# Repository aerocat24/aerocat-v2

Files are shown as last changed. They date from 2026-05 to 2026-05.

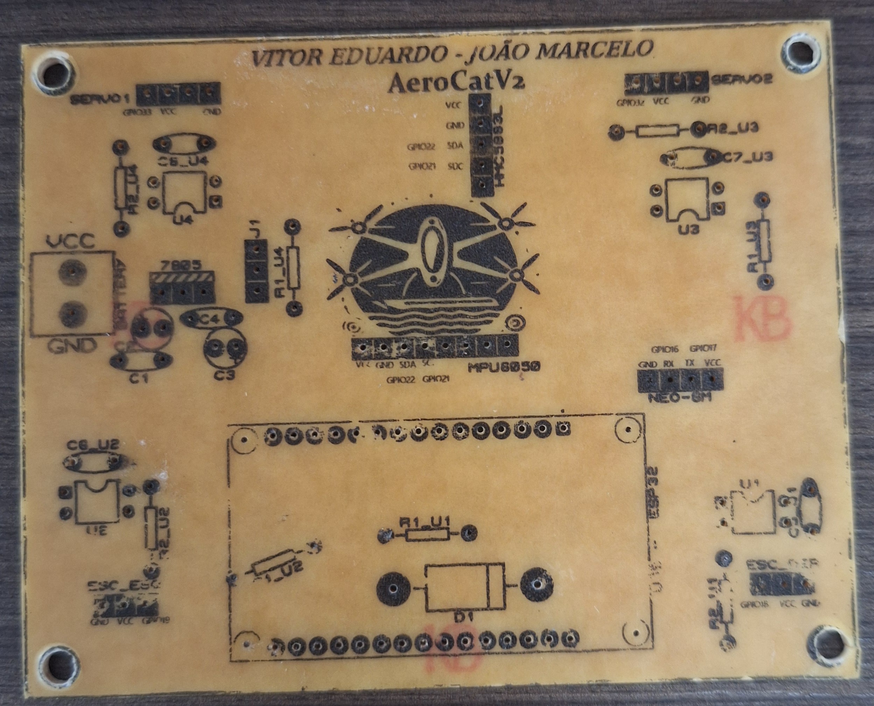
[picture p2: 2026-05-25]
PCB/images/without_components.jpg

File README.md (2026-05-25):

# ASV Aerocat V2

The **ASV Aerocat V2** is a small-scale autonomous surface vessel with a
catamaran hull and aerial propulsion. The project was developed for autonomous
navigation and for applications involving cooperation with aerial vehicles,
providing an accessible, low-cost platform for academic, educational, and
scientific research purposes.

## Development

The Aerocat V2 was developed by:

- [accaciofsantos](https://github.com/accaciofsantos)
- [joaomarcelors](https://github.com/joaomarcelors)
- [Vitaum-not](https://github.com/Vitaum-not)
- [vbschettino](https://github.com/vbschettino)

## Publications

Some results related to the project were presented in the following
publications:

- https://ieeexplore.ieee.org/document/10838066
- https://ieeexplore.ieee.org/document/11369526

## Repository Contents

This repository contains the main files required to build and replicate the
ASV Aerocat V2, including:

- assembly step-by-step instructions;
- STL files for the mechanical parts;
- PCB machining/fabrication files;
- project reference images.

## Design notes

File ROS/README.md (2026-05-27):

# ROS framework and package communication

This folder contains the ROS packages responsible for communication, navigation,
manual control, and cooperation between the AeroCat V2 ASV and the UAV. The
system was developed using ROS and operates through a Wi-Fi network connecting
the onboard computer, the ASV, and the UAV.

The framework enables autonomous navigation, real-time telemetry exchange,
remote operation, and cooperative missions such as UAV inspection and landing on
the moving ASV platform.

## ASV Quick start

### 1. Clone the repository

Clone the project to your machine:

```bash
git clone https://github.com/aerocat24/aerocat-v2.git
```

### 2. Flash the ESP32 firmware

The ESP32 firmware was developed using the PlatformIO plugin for VS Code. Open
VS Code, import the project located in the `boat_esp32` folder, build it, and
flash the firmware to your ESP32.

### 3. Build the ROS workspace

The project was developed using ROS Noetic. Go to the workspace:

```bash
cd aerocat-v2/ROS/boat_drone_ws
```

Build the workspace:

```bash
catkin build
```

### 4. Test the boat communication

With the ESP32 powered on and connected to the Wi-Fi network, start
`rosbridge`:

```bash
roslaunch rosbridge_server rosbridge_websocket.launch
```

In two other terminals, check whether the boat topics are being received:

```bash
rostopic echo /boat/compass
```

```bash
rostopic echo /boat/gps
```

If no data appears in the topics, check that:

- The computer and the ESP32 are connected to the same Wi-Fi network.
- The GPS module has signal. This is usually indicated by a blinking red light.

### 5. Check the joystick mapping

The joystick button mapping only needs to be checked once. To connect the
Bluetooth joystick to ROS, run:

```bash
roslaunch boat remote_control_joy.launch
```

In another terminal, monitor the joystick messages:

```bash
rostopic echo /boat/joy
```

Compare the received mapping with the one defined in
`remote_control_joy_node.py`. Then check whether the commands below are working
correctly:

| Control | Action |
| --- | --- |
| Left analog stick up | Sends PWM to the right motor |
| Right analog stick up | Sends PWM to the left motor |
| `L1` | Decreases the maximum power |
| `R1` | Increases the maximum power |
| `select` | Toggles between manual and autonomous mode |

When moving each analog stick, check that the corresponding motor is activated.

### 6. Start the position node

Start the boat position node:

```bash
rosrun boat position_node.py
```

Before starting autonomous navigation, update the latitude and longitude
variables in the code with the desired destination.

### 7. Start the control node

Then start the boat control node:

```bash
rosrun boat control_node.py
```

For safety, the boat does not start moving automatically. Press the `select`
button on the joystick to switch to autonomous mode. In this mode, the boat will
navigate to the GPS coordinate defined in the position node.

If the behavior is not as expected, press `select` again. The boat will return
to manual mode and stop autonomous navigation.

## Communication overview

The system architecture is divided into three main groups of nodes:

- ASV-related nodes.
- UAV-related nodes.
- Cooperative nodes responsible for interaction between both platforms.

The communication structure is based on ROS topics, where nodes publish and
subscribe to information in real time.

## Main ROS nodes

| Node | Function |
| --- | --- |
| `joy_node` | Reads Bluetooth gamepad inputs |
| `remote_control_boat` | Interprets manual commands for the ASV |
| `remote_control_tello` | Interprets manual commands for the UAV |
| `tello_driver` | Communication interface with the DJI Tello UAV |
| `aux_odom` | Applies offset corrections to UAV odometry |
| `position_p2p` | Calculates waypoint navigation parameters |
| `control_p2p` | Generates PWM commands for ASV motors |
| `interface` | Graphical interface for mission monitoring |
| `recognition` | QR code detection and landing assistance |

## Main ROS topics

| Topic | Description |
| --- | --- |
| `/Joy1` | Gamepad commands for the ASV |
| `/Joy2` | Gamepad commands for the UAV |
| `/cmd_vel` | UAV velocity commands |
| `/takeoff` | UAV takeoff command |
| `/land` | UAV landing command |
| `/status` | UAV status information |
| `/odom` | UAV visual odometry |
| `/gps` | ASV GPS data |
| `/compass` | ASV heading and orientation |
| `/distance` | Distance to the target waypoint |
| `/delta_theta` | Heading error relative to the waypoint |
| `/point_reached` | Indicates when a waypoint is reached |
| `/next_point` | Triggers navigation to the next waypoint |
| `/pwm` | PWM commands for ASV motors |
| `/camera` | UAV camera video stream |
| `/points` | Relative coordinates generated for UAV landing |

## System operation

### 1. Manual control

1. Two Bluetooth gamepads are connected to the onboard computer.
2. The `joy_node` receives joystick inputs and publishes them on the `/Joy1`
   and `/Joy2` topics.
3. The `remote_control_boat` and `remote_control_tello` nodes interpret the
   commands independently for each vehicle.
4. For the UAV, commands are converted into velocity references and published
   on `/cmd_vel`.
5. Takeoff and landing are executed through the `/takeoff` and `/land`
   topics.

## 2. ASV autonomous navigation

1. The ASV continuously publishes GPS and compass data through the `/gps`
   and `/compass` topics.
2. The `position_p2p` node calculates:
   - Distance to the target waypoint.
   - Required heading angle.
   - Waypoint completion status.
3. The computed information is published on:
   - `/distance`
   - `/delta_theta`
   - `/point_reached`
4. The `control_p2p` node converts these values into PWM motor commands.
5. PWM signals are published on the `/pwm` topic and sent to the ASV motors.
6. Once a waypoint is reached, the system waits for a `/next_point`
   command before continuing the mission.

## 3. UAV localization and monitoring

1. The `tello_driver` node provides:
   - Vehicle telemetry.
   - Battery information.
   - Flight status.
   - Visual odometry data.
2. Odometry data from `/odom` are processed by the `aux_odom` node.
3. Offset corrections are applied to improve UAV position estimation.
4. The corrected data are used for cooperative operations and landing
   assistance.

## 4. Cooperative ASV-UAV mission

1. The `interface` node provides a real-time graphical interface for:
   - Vehicle monitoring.
   - Trajectory visualization.
   - Dynamic waypoint definition.
2. During the landing procedure, a QR code marker positioned on the ASV is
   detected by the UAV camera.
3. The UAV camera stream is published on the `/camera` topic.
4. The `recognition` node processes the video stream and estimates the
   relative position between the UAV and the QR marker.
5. Landing reference coordinates are generated and published on the
   `/points` topic.
6. Using these coordinates, the UAV performs a safe landing on the moving
   ASV platform.

## Operational modes

| Mode | Description |
| --- | --- |
| Manual mode | Direct operator control using Bluetooth gamepads |
| Autonomous ASV mode | Waypoint-based autonomous navigation |
| Cooperative mode | Simultaneous ASV-UAV mission execution |
| Assisted landing mode | UAV landing using QR-code visual tracking |

## Notes

- All communication is performed over a local Wi-Fi network.
- The ASV manual control system acts as a contingency mode during autonomous
  navigation.
- Real-time cooperation depends on stable wireless communication between all
  ROS nodes.
- The UAV landing system relies on proper QR code visibility and camera
  calibration.

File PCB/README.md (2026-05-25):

# PCB and Electronics System

This folder contains the PCB files, schematics, and electronics documentation
for the ASV AeroCat V2. The board was designed to integrate the navigation
sensors, propulsion interfaces, power distribution, and communication system
into a single compact platform based on the ESP32 microcontroller.

Reference images of the schematic, PCB, and assembled electronics are available
in the [`images/`](images/) folder.

## System overview

The electronics system is responsible for:

- Navigation and orientation sensing
- Differential propulsion control
- Wireless communication
- Power regulation and distribution
- Signal isolation between control and propulsion systems

The PCB reduces the amount of external wiring by integrating the electrical
connections directly on the board.

---

# Propulsion system

The ASV AeroCat uses a differential aerial propulsion configuration composed
of two brushless propulsion units. Each unit contains a brushless motor,
an ESC, and a propeller.

Independent control of the left and right thrusters allows the vessel to
generate forward motion and turning maneuvers.

## Propulsion components

| Component | Specification | Quantity |
| --- | --- | ---: |
| ESC | Mistery 30A | 2 |
| Brushless motor | EMax CF2822 – 1200 kV | 2 |
| Propeller | 8x4.5” | 2 |

## Propulsion parameters

| Parameter | Value |
| --- | --- |
| Distance between propellers | 45 cm |
| Maximum surge force | 9.43 N |
| Maximum yaw torque | ±1.06 N·m |

---

# Navigation system

The navigation system is based on the ESP32 DevKit V2 platform and integrates
positioning, orientation, and inertial sensing modules directly into the PCB.

Compared to earlier versions that used jumper connections, the custom PCB
provides a cleaner organization and improves the integration between sensors,
actuators, and the control system.

## Navigation components

| Component | Function | Quantity |
| --- | --- | ---: |
| ESP32 DevKit V2 | Main controller | 1 |
| GY-NEO6M GPS | Global positioning | 1 |
| HMC5883L | Compass sensor | 1 |
| MPU6050 | Inertial measurement unit | 1 |

The GPS module provides positioning data, while the HMC5883L is used for
heading estimation. The MPU6050 is included for inertial sensing and future
sensor fusion applications.

---

# Communication system

The communication system uses the integrated wireless capabilities of the ESP32.

## Communication features

- Wi-Fi communication with the base station
- Bluetooth support for short-range operation
- Remote telemetry transmission
- Reception of navigation and control commands

During experimental operation, Wi-Fi was used as the primary communication
channel between the vessel and the base station.

---

# PCB integration

The PCB centralizes the electrical connections between sensors, propulsion
interfaces, power regulation, and control signals.

## Integrated components

| Component | Description | Quantity |
| --- | --- | ---: |
| ESP32 DevKit V2 | Main microcontroller board | 1 |
| GY-NEO6M | GPS module connector | 1 |
| HMC5883L | Compass connector | 1 |
| MPU6050 | IMU connector | 1 |
| PC817 | Optocoupler | 4 |
| 7805 | Voltage regulator | 1 |
| 1N5400 | Protection diode | 1 |
| Capacitor 100 pF | Signal and power filtering | 6 |
| Capacitor 1 µF | Voltage filtering | 1 |
| Resistor 330 Ω | Optocoupler input resistor | 4 |
| Resistor 10 kΩ | Pull-down resistor | 4 |
| ESC connectors | ESC signal outputs | 2 |
| Servo connectors | Servo outputs | 2 |
| Battery connector | Main power input | 1 |
| Power connector J1 | Auxiliary power connection | 1 |

## PCB functions

The PCB integrates:

- ESP32 communication and control interface
- GPS serial communication
- I2C communication for compass and MPU6050
- PWM outputs for ESC control
- PWM outputs for servo connections
- Battery power input
- 5 V voltage regulation
- Signal isolation using optocouplers
- Power filtering and stabilization

The schematic defines the relationship between the propulsion system,
navigation sensors, power electronics, and the ESP32 control platform.

---

# Electronics installation

All electronics should be installed inside the central module of the vessel.

## Installation guidelines

1. Install the PCB inside the electronics compartment.
2. Connect the GPS, compass, and MPU6050 modules to their headers.
3. Connect the ESC signal lines to the PCB outputs.
4. Connect the battery to the power input terminals.
5. Route the motor wires toward the propulsion supports.
6. Verify all power and signal connections before powering the system.
7. Ensure proper insulation and protection against humidity inside the module.

---

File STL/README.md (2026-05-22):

# STL files and assembly

This folder contains the STL files for printing the mechanical parts of the
small AeroCat V2 catamaran. Reference images for each part are available in the
[`images/`](images/) folder.

## Printing information

- Material: ABS for all parts, except the front hull guard
  (`13_front_hull_guard.stl`), which should be printed in TPU.
- Layer height: 0.2 mm.
- General infill: 10%.
- Infill for `08_module_hull_handle.stl`: 30%.
- Infill for `13_front_hull_guard.stl`: 5%.

Before starting the assembly, note that a 0.2 mm clearance was left for the
part fits. Because of this, it may be necessary to sand some joints before the
final assembly.

## Parts to print

| File | Description | Quantity |
| --- | --- | ---: |
| `01_front_hull.stl` | Front hull | 2 |
| `02_right_middle_hull.stl` | Right middle hull | 1 |
| `03_left_middle_hull.stl` | Left middle hull | 1 |
| `04_right_rear_hull.stl` | Right rear hull | 1 |
| `05_left_rear_hull.stl` | Left rear hull | 1 |
| `06_small_hull_cover.stl` | Small cover for the front and rear hull sections | 4 |
| `07_large_hull_cover.stl` | Large cover for the middle hull section | 2 |
| `08_module_hull_handle.stl` | Handle that connects the hull to the central module | 4 |
| `09_motor_base.stl` | Motor base | 2 |
| `10_motor_base_cover.stl` | Motor base cover | 2 |
| `11_module.stl` | Central module | 1 |
| `12_module_cover.stl` | Central module cover | 1 |
| `13_front_hull_guard.stl` | Front hull guard | 2 |
| `14_front_platform_base.stl` | Front platform base | 2 |
| `15_rear_platform_base.stl` | Rear platform base | 2 |
| `16_large_platform_channel.stl` | Large platform channel | 4 |
| `17_small_platform_channel.stl` | Small platform channel | 4 |
| `18_large_platform_channel_support.stl` | Support for the large platform channels | 2 |
| `19_platform_base_diagonal_channel_support_1.stl` | Main diagonal platform base support | 2 |
| `20_platform_base_diagonal_channel_support_2.stl` | Secondary diagonal platform base support | 2 |
| `21_small_platform_channel_support.stl` | Support for the small platform channels | 2 |
| `22_platform_center_support.stl` | Platform center support | 1 |

## Additional items

| Item | Use | Quantity |
| --- | --- | ---: |
| M4 25 mm screw + nut + washer | Fastening the bases, handles, and platform | 24 units |
| M3 16 mm screw + nut + washer | Smaller fasteners | 2 units |
| Sealing silicone | Sealing the hull joints | As needed |
| Bicycle spokes | Auxiliary platform structure | 4 units |
| Hot glue | Locking and finishing the platform joints | As needed |
| Nylon line | Platform side protection | As needed |
| 50 x 30 cm acrylic sheet | Platform floor | 1 unit |

## Assembly steps

### 1. Hull assembly

1. Assemble the right hull by fitting parts `01`, `02`, and `04` together.
2. Assemble the left hull by fitting parts `01`, `03`, and `05` together.
3. Before making each final joint, apply sealing silicone to the connections to
   prevent water from entering.
4. Install the front hull guards `13` on the bow of both hulls.
5. Wait for the silicone to cure according to the manufacturer's
   recommendation before moving on to the next steps.

### 2. Connecting the hulls to the central module

1. With both hulls assembled, connect the four handles `08` to the hulls.
2. Connect the four handles `08` to the central module `11`.
3. Install the motor bases `09` and their covers `10`.
4. Install the large middle hull covers `07`.
5. Fasten the motor bases `09` and the handles `08` using M4 screws.

### 3. Assembly without the platform

1. Fit the four small hull covers `06` onto the front and rear hull sections.
2. Check that all covers are properly seated and sealed.

### 4. Assembly with the platform

1. Connect two large platform channels `16` using the support `18`.
2. Fit the 50 x 30 cm acrylic sheet.
3. Close the structure by adding the small platform channels `17` with the
   supports `21`.
4. Connect the diagonal supports `19` and `20`.
5. From the underside of the platform, connect the bicycle spokes to the center
   support `22` and to the channel supports `18` and `21`.
6. Thread the nylon line through the holes in the channels. This line acts as
   protection to prevent the aerial vehicle from leaving the platform.
7. Apply hot glue between the platform joints.
8. With the platform ready, connect the bases `14` and `15` to the boat hulls
   and to the platform.
9. Fasten the four corners with M4 screws.

### 5. Electronics

All electronics should be placed inside the central module `11`. The motor
wires should pass through the rear handles `08` and go up through the motor
bases `09`.

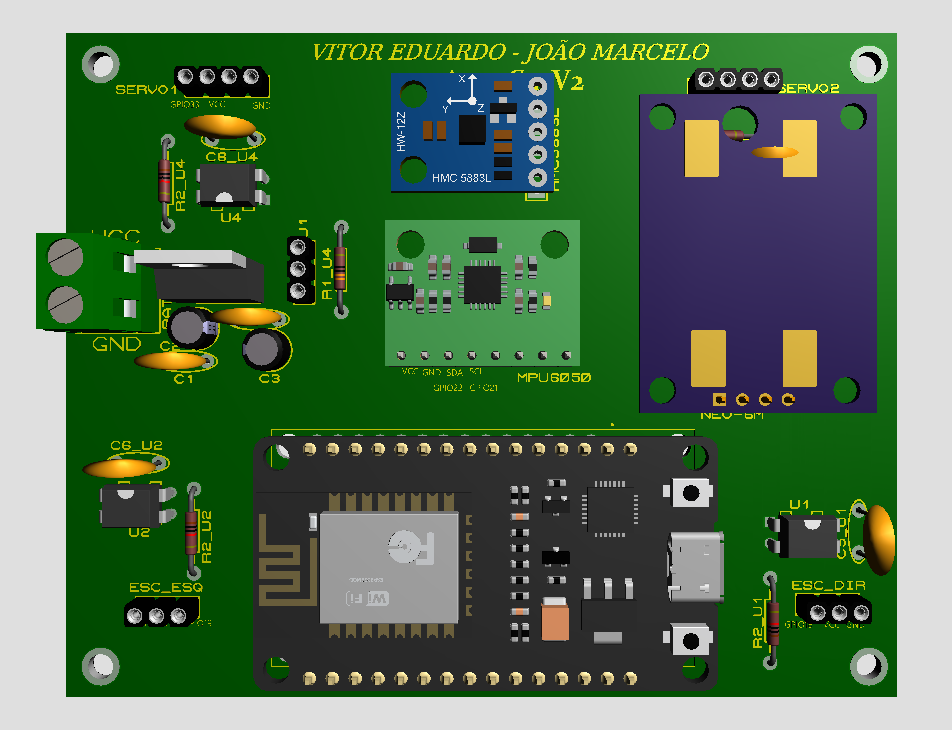
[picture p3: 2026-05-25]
PCB/images/pcb_designed.png

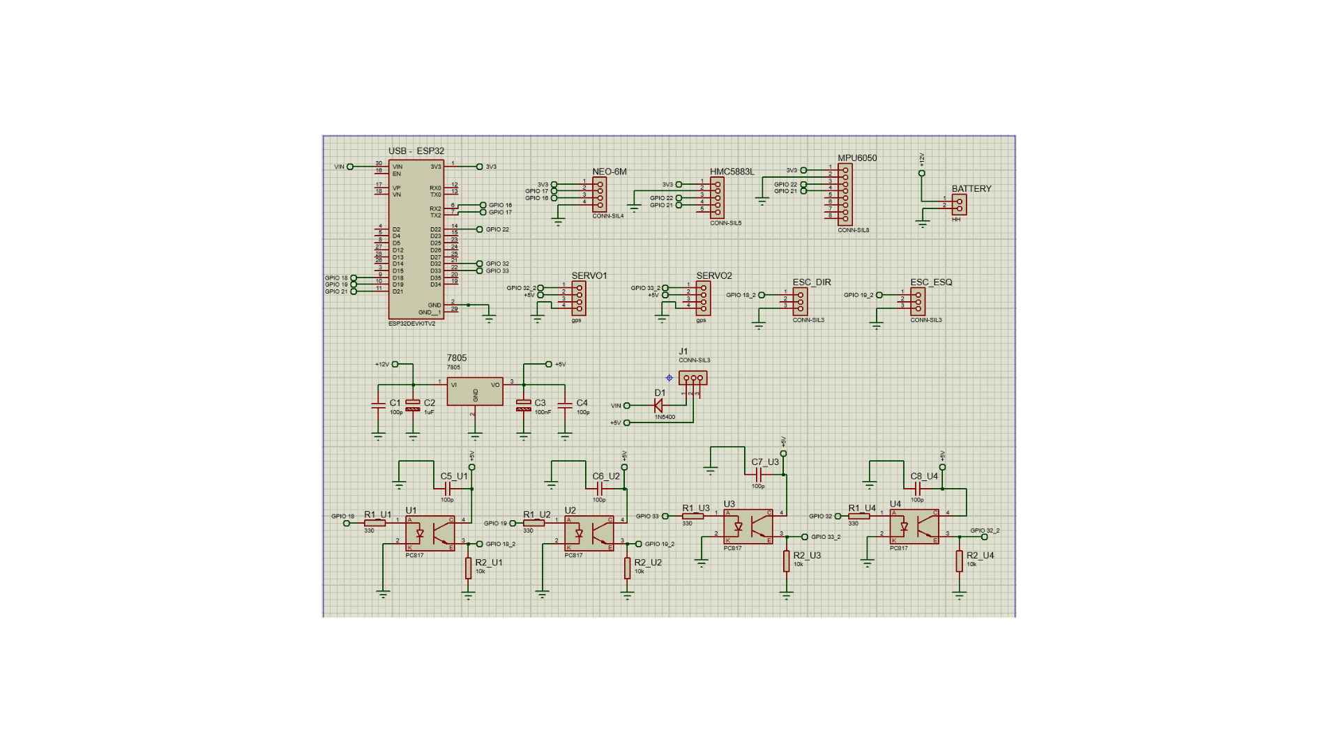
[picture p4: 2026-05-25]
PCB/images/Schematic.png

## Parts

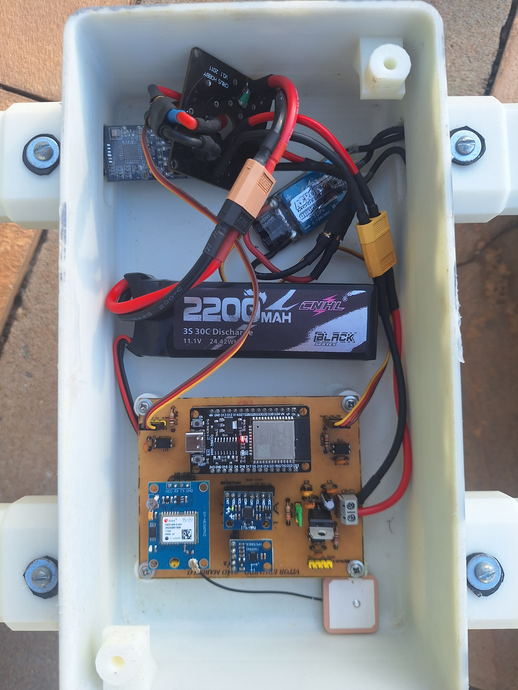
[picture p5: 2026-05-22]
images/components_module.jpg

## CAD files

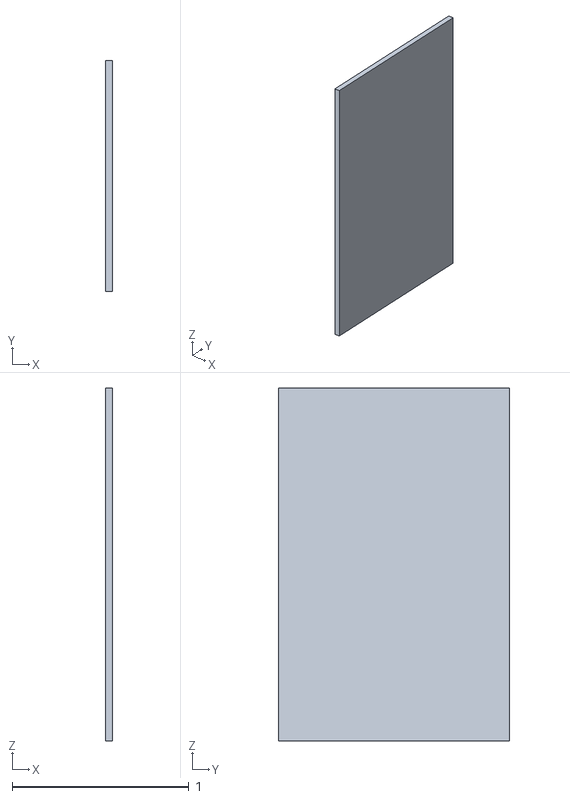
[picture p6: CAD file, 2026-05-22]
ROS/boat_drone_ws/src/hector_quadrotor_noetic/hector_gazebo/hector_gazebo_worlds/Media/models/sick_robot_panel.stl
0.04 x 1.31 x 2.00

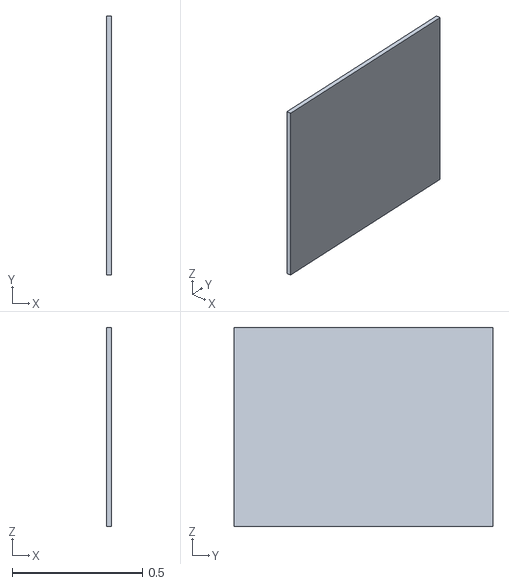
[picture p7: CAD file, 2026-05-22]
ROS/boat_drone_ws/src/hector_quadrotor_noetic/hector_models/hector_components_description/meshes/checkerboard/checkerboard.stl
0.02 x 0.993 x 0.763

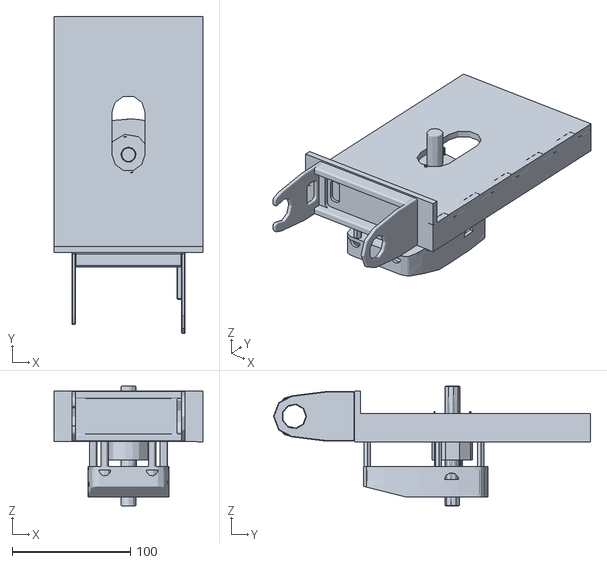
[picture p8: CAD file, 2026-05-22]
ROS/boat_drone_ws/src/hector_quadrotor_noetic/hector_models/hector_components_description/meshes/hector_multisensor_head/multisensor_head.stl
126.0 x 268.5 x 101.6

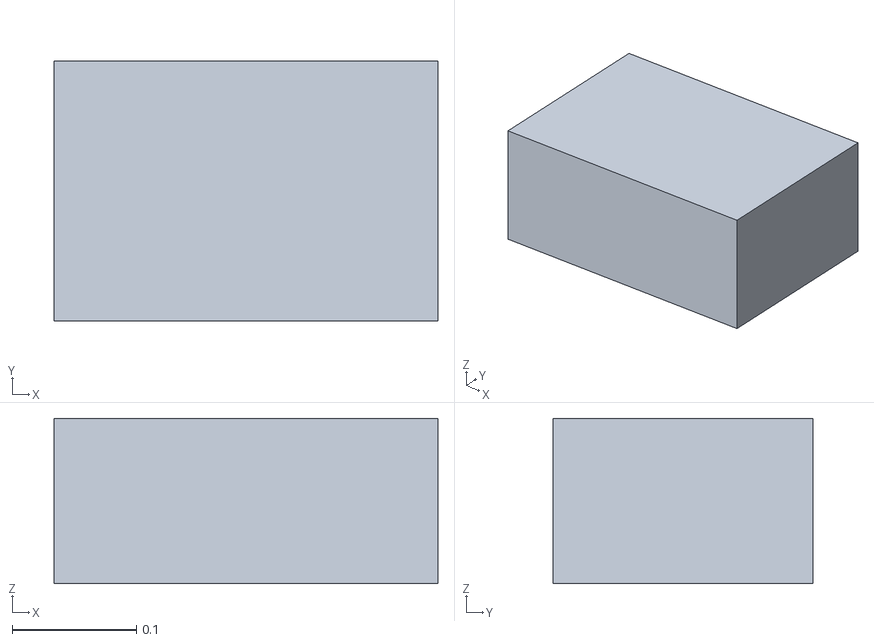
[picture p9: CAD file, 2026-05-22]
ROS/boat_drone_ws/src/hector_quadrotor_noetic/hector_models/hector_components_description/meshes/vision_box/hector2_top_box.stl
0.309 x 0.209 x 0.133

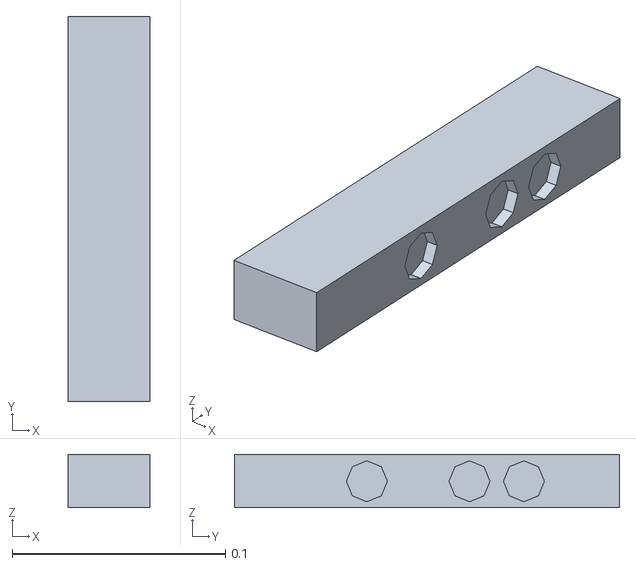
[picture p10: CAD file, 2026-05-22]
ROS/boat_drone_ws/src/hector_quadrotor_noetic/hector_models/hector_sensors_description/meshes/asus_camera/asus_camera_simple.stl
0.0384 x 0.18 x 0.025

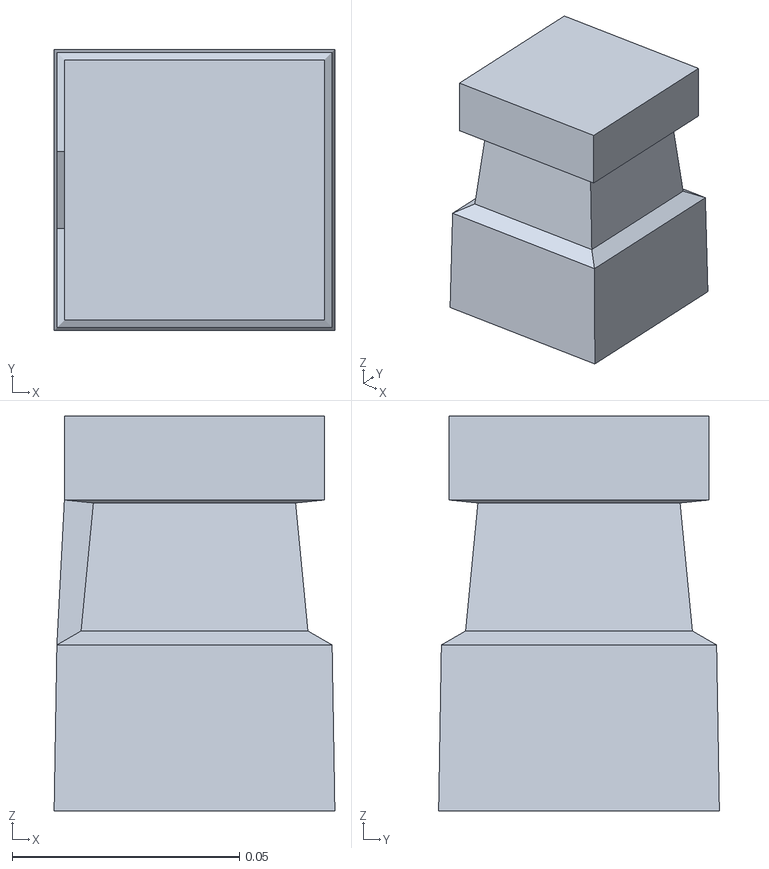
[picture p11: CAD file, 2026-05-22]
ROS/boat_drone_ws/src/hector_quadrotor_noetic/hector_models/hector_sensors_description/meshes/hokuyo_utm30lx/hokuyo_utm_30lx.stl
0.0618 x 0.0618 x 0.087

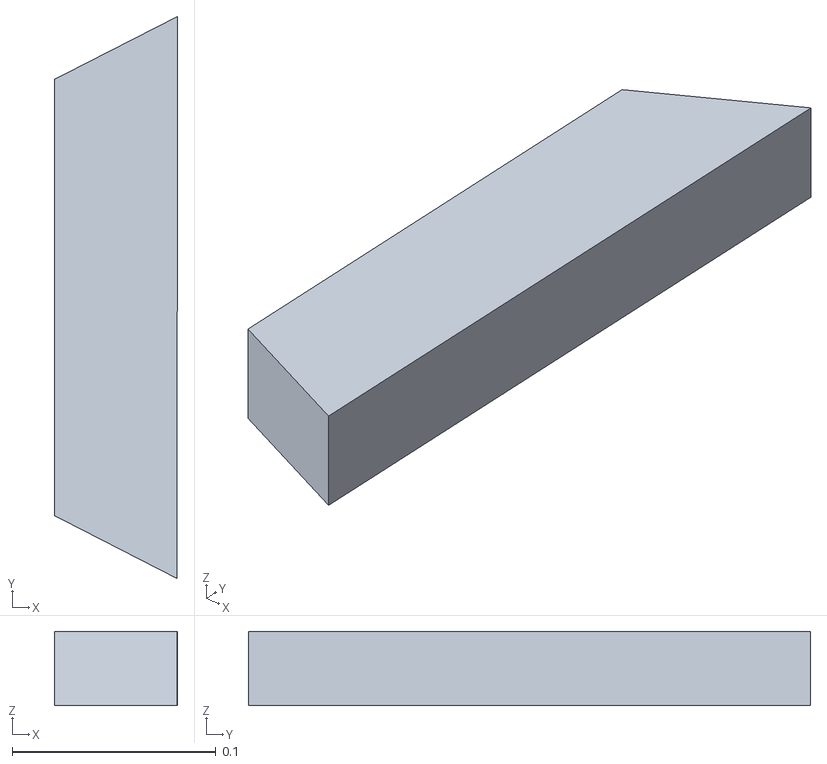
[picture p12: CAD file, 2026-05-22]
ROS/boat_drone_ws/src/hector_quadrotor_noetic/hector_models/hector_sensors_description/meshes/kinect_camera/kinect_camera_simple.stl
0.0604 x 0.276 x 0.0364

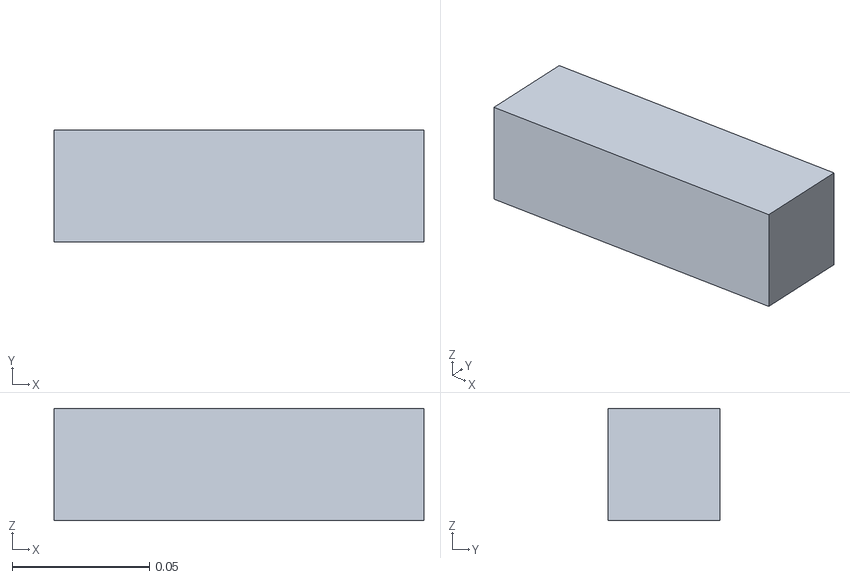
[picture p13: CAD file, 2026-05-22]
ROS/boat_drone_ws/src/hector_quadrotor_noetic/hector_models/hector_sensors_description/meshes/thermaleye_camera/thermaleye_camera_hector_v2.stl
0.135 x 0.041 x 0.041

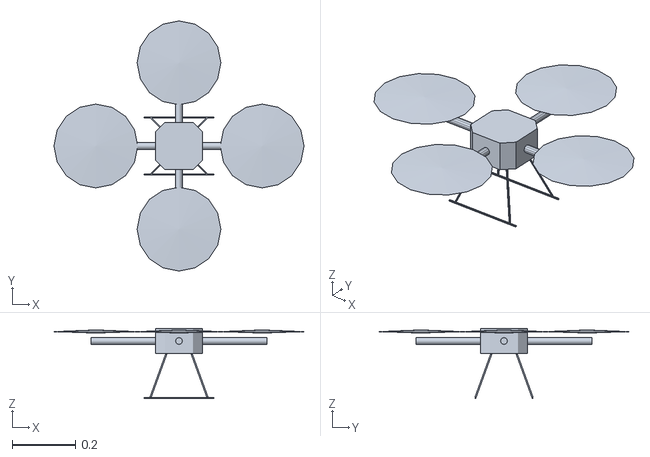
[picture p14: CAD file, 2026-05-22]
ROS/boat_drone_ws/src/hector_quadrotor_noetic/hector_quadrotor/hector_quadrotor_description/meshes/quadrotor/quadrotor_base.stl
0.791 x 0.791 x 0.222

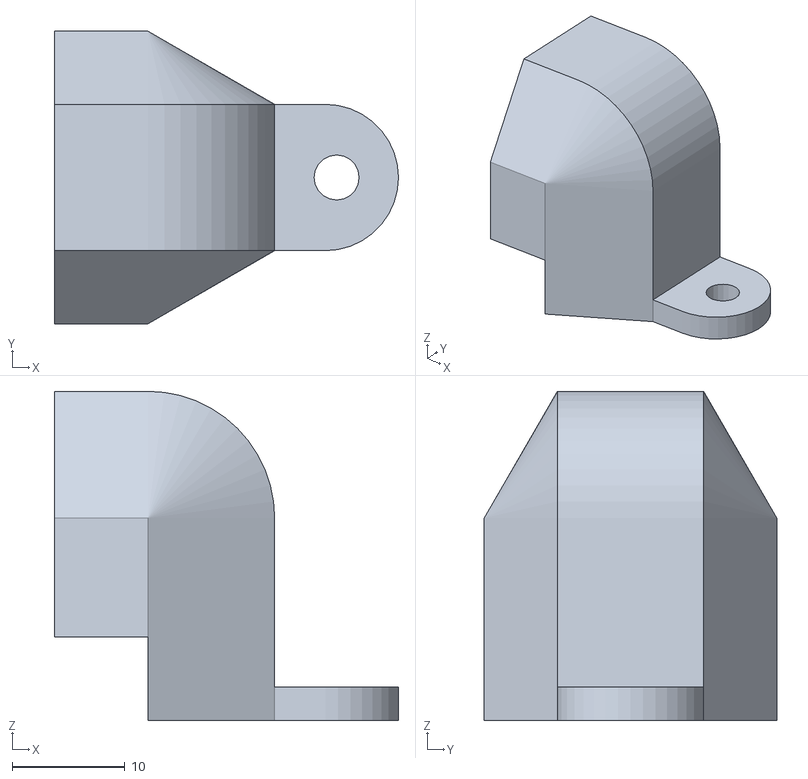
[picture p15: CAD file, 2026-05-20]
STL/10_motor_base_cover.stl
30.6 x 26.0 x 29.3

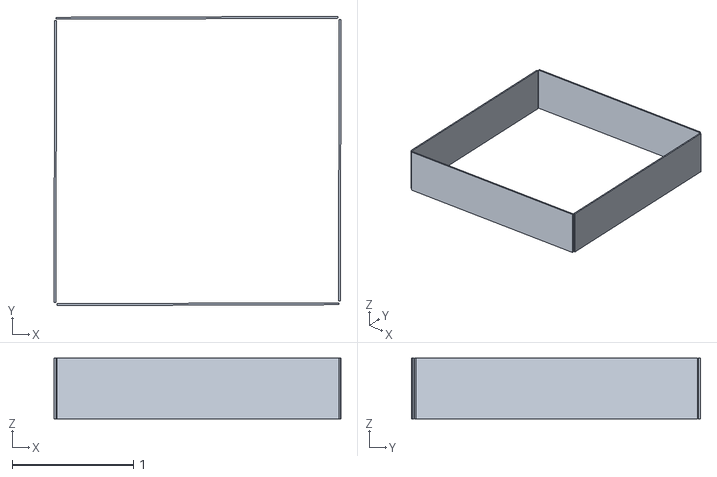
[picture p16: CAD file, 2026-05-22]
ROS/boat_drone_ws/src/hector_quadrotor_noetic/hector_gazebo/hector_gazebo_worlds/Media/models/sick_robot_day_2014_inner_block.stl
2.37 x 2.39 x 0.5

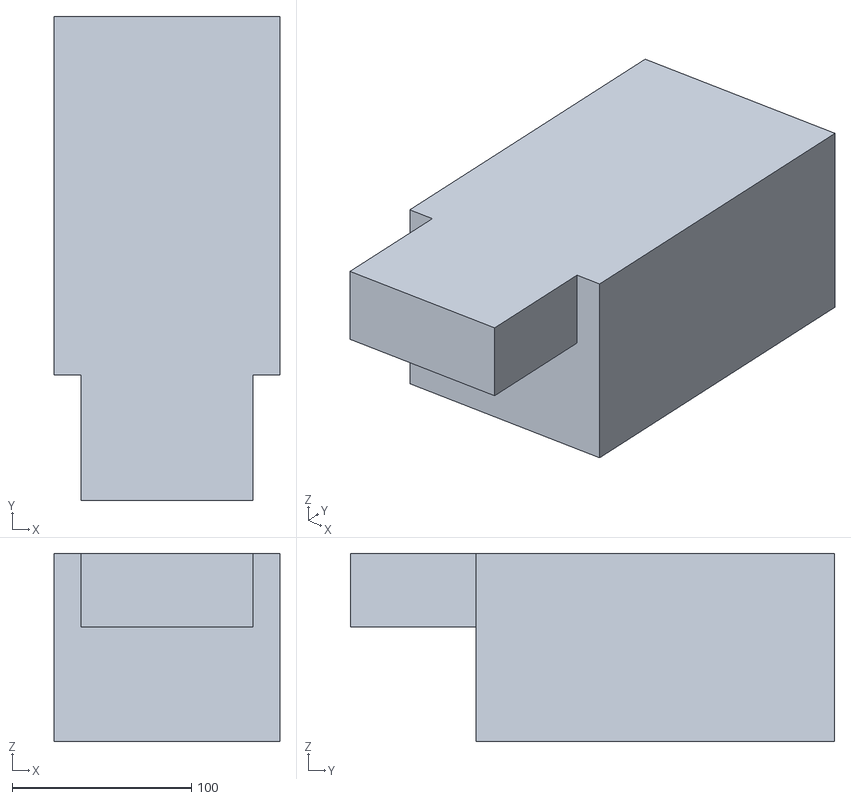
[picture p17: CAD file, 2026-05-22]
ROS/boat_drone_ws/src/hector_quadrotor_noetic/hector_models/hector_components_description/meshes/hector_multisensor_head/multisensor_head_collision.stl
126.0 x 270.0 x 105.0

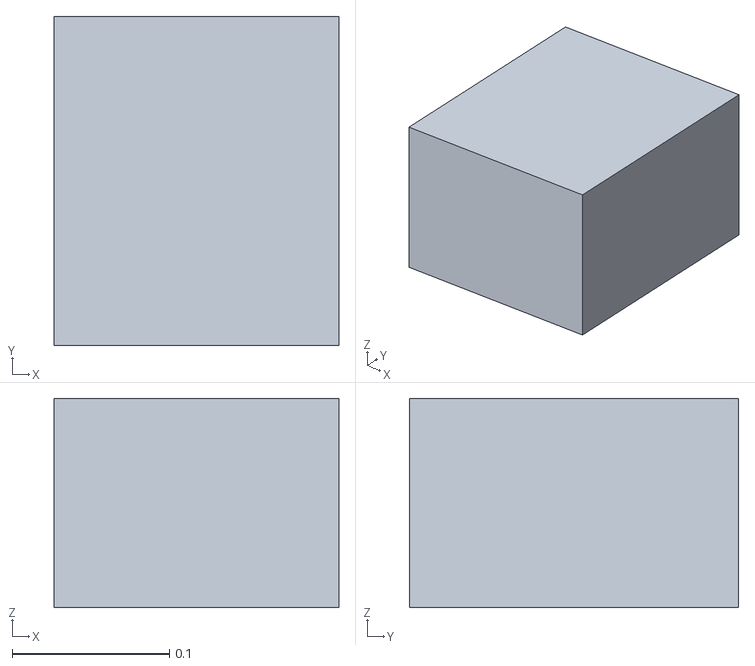
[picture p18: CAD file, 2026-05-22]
ROS/boat_drone_ws/src/hector_quadrotor_noetic/hector_models/hector_components_description/meshes/vision_box/hector1_top_box.stl
0.181 x 0.209 x 0.133

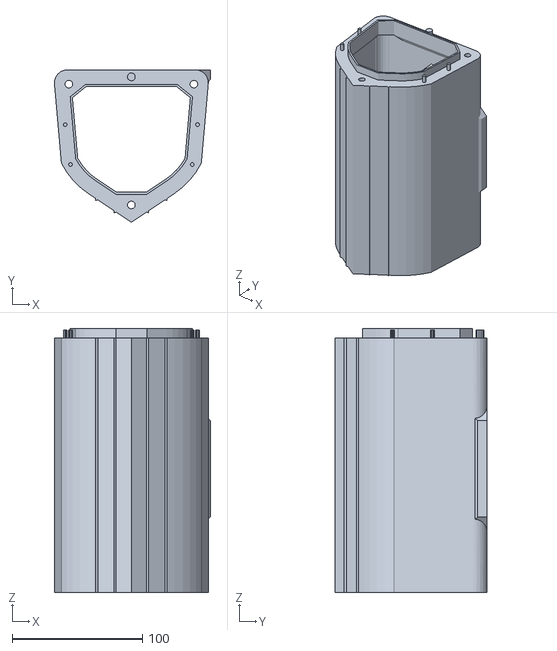
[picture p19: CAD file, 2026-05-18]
STL/02_right_middle_hull.stl
119.8 x 117.0 x 202.7

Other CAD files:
ROS/boat_drone_ws/src/hector_quadrotor_noetic/hector_gazebo/hector_gazebo_worlds/Media/models/sick_robot_day_2014_target.stl
STL/14_front_platform_base.stl
ROS/boat_drone_ws/src/hector_quadrotor_noetic/hector_gazebo/hector_gazebo_worlds/Media/models/drc_qual4_block.stl
STL/16_large_platform_channel.stl
ROS/boat_drone_ws/src/hector_quadrotor_noetic/hector_gazebo/hector_gazebo_worlds/Media/models/sick_robot_day_2014_ring.stl
ROS/boat_drone_ws/src/hector_quadrotor_noetic/hector_models/hector_sensors_description/meshes/hokuyo_utm30lx/blender/hokuyo_utm30lx.blend
ROS/boat_drone_ws/src/hector_quadrotor_noetic/hector_models/hector_sensors_description/meshes/sonar_sensor/blender/max_sonar_ez4.blend
ROS/boat_drone_ws/src/hector_quadrotor_noetic/hector_models/hector_sensors_description/meshes/thermaleye_camera/thermaleye_camera_hector_v1.stl
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

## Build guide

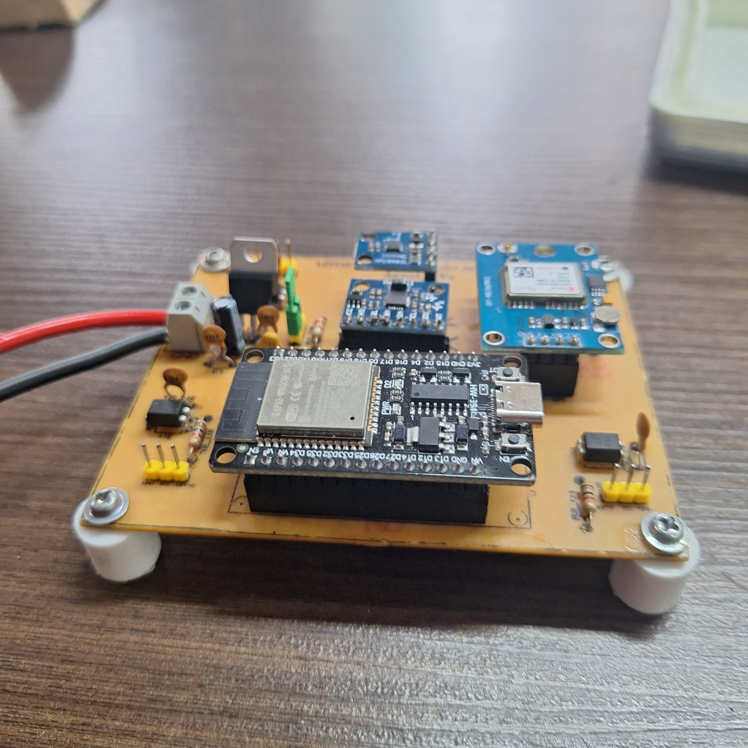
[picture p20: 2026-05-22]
images/assembled PCB_2.jpg

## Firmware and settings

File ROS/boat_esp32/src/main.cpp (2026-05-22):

#include "comunnication.h"
#include "general_function.h"
#include "header.h"
#include <Arduino.h>

void setup() {

  Serial.begin(115200);

  // configuração bussula
  compass.init();
  compass.setCalibrationOffsets(-184.00, -30.00, 163.00);
  compass.setCalibrationScales(0.79, 0.78, 2.17);

  // configuração gps
  SerialGPS.begin(GPS_BAUD, SERIAL_8N1, GPS_RX_PIN, GPS_TX_PIN);

  wifi_init();

  esc_left.attach(PWM_LEFT_PIN, 1000, 2000);
  esc_right.attach(PWM_RIGHT_PIN, 1000, 2000);

  //tempo para a configuração dos esc's
  delay(7000);  

  esc_left.write(0);  // pwm inicial
  esc_right.write(0); // pwm inicial

  pwmSemaphore = xSemaphoreCreateBinary(); //cria semáforo binário
  xSemaphoreGive(pwmSemaphore); // coloca como disponível

  xTaskCreatePinnedToCore(
    taskSendData,       // função da tarefa
    "taskSendData",     // nome
    4096,                 // stack
    NULL,                 // param
    1,                    // prioridade
    NULL,                 // handle
    1                    // núcleo (ESP32 core 1)
  );
}

void loop() {
  
  //verifica se tem eventos acontecendo no callback
  webSocket.loop();

}

void taskSendData(void *pvParameters){
  
  while(1){

    if (WiFi.status() == WL_CONNECTED && webSocket.isConnected())  {

      while (SerialGPS.available() > 0) {
        gps.encode(SerialGPS.read());
      }
  
      if (gps.location.isUpdated()) {
  
        gps_lat = gps.location.lat();
        gps_lng = gps.location.lng();
  
        // ler valor da bussula
        compass.read();
        angle = compass.getAzimuth() -30;
  
        // normaliza o angulo para a faixa [-180, 180)
  
        if (angle > 180) {
          angle -= 360;
        } else if (angle < -180) {
          angle += 360;
        }
  
        Serial.print("LAT: ");
        Serial.println(gps_lat, 8);
        Serial.print("LONG: ");
        Serial.println(gps_lng, 8);
  
        Serial.print("angle: ");
        Serial.println(angle);
        Serial.println("");
        
        //verifica se o semaforo está disponivel
        if (xSemaphoreTake(pwmSemaphore, portMAX_DELAY) == pdTRUE) {
          // publica o pwm hold
          ros_pub_int32_multiarray(pub_topic_pwm_hold, pwm_left_hold, pwm_right_hold);
          xSemaphoreGive(pwmSemaphore);
        }
        // publica o gps
        ros_pub_float32_multiarray(pub_topic_gps, gps_lat, gps_lng);
        // publica a bussula
        ros_pub_int32(pub_topic_compass, angle);
      }
  
    } 
    vTaskDelay(pdMS_TO_TICKS(50));
  }
}

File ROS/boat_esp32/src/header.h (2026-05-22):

#pragma once
#include <Arduino.h>
#include <ArduinoJson.h>
#include <WiFi.h>
#include <freertos/FreeRTOS.h>
#include <freertos/task.h>
#include <freertos/semphr.h>
#include <WebSocketsClient.h>
#include <ESP32Servo.h>
#include <QMC5883LCompass.h>
#include <Wire.h>
#include <TinyGPS++.h>
#include <HardwareSerial.h>
#include <Adafruit_MPU6050.h>
#include <Adafruit_Sensor.h>
#include <ArduinoEigenDense.h>

#define PWM_LEFT_PIN 19
#define PWM_RIGHT_PIN 18
#define GPS_RX_PIN 16 // Pino RX do ESP32 para o módulo GPS
#define GPS_TX_PIN 17  // Pino TX do ESP32 para o módulo GPS
#define GPS_BAUD 9600
#define TYPE_COMMUNICATION 2 // 1 WiFI 2 Ethernet

#define INTERVAL 500

const char* ssid = "tp-link_ROS";
const char* password = "sirolab2024";

// Configuração do WebSocket
WebSocketsClient webSocket;
#if TYPE_COMMUNICATION == 1
    const char *rosbridge_address =  "192.168.0.105"; // Endereço do servidor ROS (rosbridge), IP do meu computador
#else 
    const char *rosbridge_address =  "192.168.0.106"; // Endereço do servidor ROS (rosbridge), IP do meu computador
#endif

//192.168.0.100 ethernet
//192.168.0.101 wifi
const int rosbridge_port = 9090;

int pwm_left_hold = 0.0;
int pwm_right_hold = 0.0;

float gps_lat;
float gps_lng;

int angle;

//Publishers
const char *pub_topic_compass = "/boat/compass";
const char *pub_topic_gps = "/boat/gps";
const char *pub_topic_pwm_hold = "/boat/pwm_hold";

//Subscribers
const char *sub_topic_pwm = "/boat/pwm";

void ros_pub_int32(String topic, int data);
void ros_pub_int32_multiarray(String topic, int data1, int data2);
void ros_pub_float32_multiarray(String topic, double data1, double data2);
void webSocketEvent(WStype_t type, uint8_t *payload, size_t length);
void pwm_write(int pwm_left, int pwm_right);
void taskSendData(void *pvParameters);

Servo esc_left; // motor direito
Servo esc_right; // motor direito

// Objeto TinyGPS++ para trabalhar com os dados do GPS
TinyGPSPlus gps;

// Comunicação Serial para comunicar-se com GPS
HardwareSerial SerialGPS(2); // Use a porta serial 2 do ESP32 (Serial2)
QMC5883LCompass compass;


SemaphoreHandle_t pwmSemaphore;

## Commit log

2026-05-18 Add STL files of the boat parts.
    [01_front_hull.stl, 02_right_middle_hull.stl, 03_left_middle_hull.stl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]
2026-05-20 Add motor base cover and index refactoring
    [10_motor_base_cover.stl, 11_module.stl, 12_module_cover.stl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]
2026-05-20 Add images to help with assembling the boat.
2026-05-22 Add ROS packages for the boat and drone and ESP32 code.
    [Tello.cfg, asus_camera.urdf.xacro, asus_camera_simple.stl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]
2026-05-22 Add boat PCB fabrication files.
    [pcb_aerocat - CADCAM Bottom Copper.GBR, pcb_aerocat - CADCAM Bottom Solder Resist.GBR, pcb_aerocat - CADCAM Drill TOP-BOT NonPlated.GBR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]
2026-05-22 Add README for STL files and assembly instructions
2026-05-25 Expand README with PCB and electronics details
    Added detailed documentation about the PCB and its components, including propulsion, navigation, and communication systems.
2026-05-25 Revise README for PCB and electronics documentation
    Updated the README.md to enhance clarity and detail about the PCB and electronics system for ASV AeroCat V2. Improved descriptions of components, systems, and installation guidelines.
